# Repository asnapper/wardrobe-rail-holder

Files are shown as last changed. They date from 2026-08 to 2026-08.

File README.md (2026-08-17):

# Ceiling wardrobe rail bracket

Parametric OpenSCAD model for mounting a vertical 30 × 15 mm rounded-rectangle
wardrobe rail to a ceiling. The rail has 7 mm corner radii and is captured by a
removable lower cap.

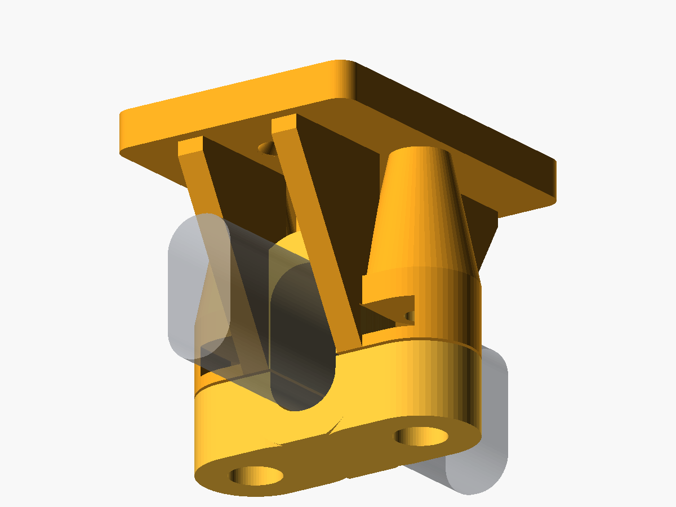
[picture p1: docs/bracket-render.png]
Rendered wardrobe rail bracket


## Hardware for one bracket

- 2 × M6 × 12 mm button-head socket screws
- 2 × standard M6 hex nuts (10 mm nominal across flats, 6 mm thick)
- 2 × 4 mm countersunk ceiling screws
- Ceiling anchors appropriate for the ceiling construction and intended load

Do not select ceiling anchors by screw size alone. Plasterboard, masonry,
concrete, timber, and suspended ceilings require different fastening methods.

## Release files

| File | Contents and intended use |
| --- | --- |
| [`dist/models/wardrobe_rail_bracket_main.stl`](dist/models/wardrobe_rail_bracket_main.stl) | Main body in its recommended print orientation; use with any slicer. |
| [`dist/models/wardrobe_rail_bracket_cap.stl`](dist/models/wardrobe_rail_bracket_cap.stl) | Cap in its recommended print orientation; use with any slicer. |
| [`dist/models/wardrobe_rail_bracket_main.3mf`](dist/models/wardrobe_rail_bracket_main.3mf) | Neutral, portable 3MF containing the main body only. |
| [`dist/models/wardrobe_rail_bracket_cap.3mf`](dist/models/wardrobe_rail_bracket_cap.3mf) | Neutral, portable 3MF containing the cap only. |
| [`dist/models/wardrobe_rail_bracket_complete.3mf`](dist/models/wardrobe_rail_bracket_complete.3mf) | Neutral, portable print layout containing one main body and one cap. |
| [`dist/wardrobe_rail_bracket_P1S_0.4_PLA_2x.gcode.3mf`](dist/wardrobe_rail_bracket_P1S_0.4_PLA_2x.gcode.3mf) | Ready-to-print Bambu Lab P1S project for two complete brackets, with models, project settings, and printer toolpaths. |

The P1S project was sliced with OrcaSlicer 2.4.2 for a P1S with a 0.4 mm
nozzle, Textured PEI Plate, and Bambu PLA Basic. It contains four objects: two
main bodies and two caps. Its embedded profile uses 0.20 mm layers, 5 walls, 6
top and bottom layers, 40% gyroid infill, a 5 mm outer brim with a 0.1 mm gap,
and no supports. OrcaSlicer reports 250 layers, 169.15 g of filament, and
22,314 s (about 6 h 12 min) estimated print time.

The headless P1S build is intended to reproduce the project settings and
toolpaths; embedded thumbnails are not guaranteed. Review the selected filament
and build plate in OrcaSlicer before sending it to the printer.

OrcaSlicer retains its standard enclosed-printer PLA advisory because the stock
Textured PEI profile uses a 55 °C bed. For this long PLA print, open the P1S
front door and/or remove the upper glass so chamber heat does not soften the
filament and cause an extruder clog. The advisory is intentionally retained; the
material heat limit and official bed temperature have not been falsified to hide
it.

## Reproducing release assets

Install [Python 3](https://www.python.org/downloads/),
[OpenSCAD](https://openscad.org/downloads.html), and
[OrcaSlicer 2.4 or later](https://github.com/OrcaSlicer/OrcaSlicer/releases).
Python 3 runs the standard-library artifact validator that checks every staged
model and sliced project before any release file is replaced.
[`xvfb-run`](https://packages.ubuntu.com/search?keywords=xvfb) is optional for
the aggregate release build: without it, `build-all.sh` still builds the models
and P1S project but preserves the existing render. It is required whenever
`build-render.sh` regenerates the PNG, including on a machine with a display.

Run the individual builders from the repository root:

```bash
./scripts/build-models.sh  # neutral STL and 3MF files in dist/models
./scripts/build-p1s.sh     # sliced P1S .gcode.3mf in dist
./scripts/build-render.sh  # regenerates docs/bracket-render.png; requires Xvfb
./scripts/build-all.sh     # models and P1S project; regenerates render if Xvfb is available
```

The builders locate `python3`, `openscad`, `orca-slicer` (also `orcaslicer` or
`OrcaSlicer`), and `xvfb-run` on `PATH`. Set `PYTHON_BIN`, `OPENSCAD_BIN`,
`ORCASLICER_BIN`, or `XVFB_RUN_BIN` to executable paths to override those
selections, for example:

```bash
PYTHON_BIN=/opt/python/bin/python3 ./scripts/build-models.sh
OPENSCAD_BIN=/opt/OpenSCAD/openscad ./scripts/build-models.sh
ORCASLICER_BIN=/opt/OrcaSlicer/orca-slicer ./scripts/build-p1s.sh
XVFB_RUN_BIN=/usr/bin/xvfb-run ./scripts/build-render.sh
```

`build-models.sh` accepts `--output-dir DIR`; `build-p1s.sh` and
`build-render.sh` accept `--output FILE`. `build-all.sh` has no arguments. If
Xvfb is unavailable, `build-all.sh` warns and keeps the existing render rather
than replacing it.

## Exporting the parts

Open `wardrobe_rail_bracket.scad` in OpenSCAD and set `part` near the top of the
file:

```scad
part = "main_print"; // main part in its recommended print orientation
part = "cap_print";  // cap in its recommended print orientation
```

The default `part = "print"` places both pieces on the build plate in their
recommended orientations. `part = "assembly"` shows the installed arrangement;
OpenSCAD preview also displays a translucent reference rail.

Command-line export is supported:

```bash
openscad -o wardrobe-bracket-main.stl -D 'part="main_print"' wardrobe_rail_bracket.scad
openscad -o wardrobe-bracket-cap.stl -D 'part="cap_print"' wardrobe_rail_bracket.scad
```

The `main` and `cap` modes retain the installed assembly coordinates and are
useful for CAD inspection rather than direct slicing.

All principal dimensions are top-level parameters. The default rail socket is
30.6 × 15.6 mm with a 7.3 mm radius, providing 0.3 mm nominal clearance on each
side, and the top of the rail sits 30 mm below the ceiling-contact plane. Print
a short fit sample or adjust `rail_clearance` if the printer or rail needs a
different tolerance.

## Suggested PLA print settings

- 0.2 mm layer height or finer
- At least 5 perimeters/walls
- At least 6 top and bottom layers
- 40–60% cubic or gyroid infill
- No supports should be required in the supplied print layout; inspect the
  preview for the selected printer and slicer

The main part prints with its ceiling-contact face on the bed. The cap has a
flattened exterior face for bed adhesion; its downward-facing bolt-head recesses
start at that face and print upward from the build plate. Avoid changing these
orientations casually: layer direction is part of the load-bearing design.

PETG or another tougher, more creep-resistant material is preferable for warm
locations or long-term heavy loading. If using a material other than PLA,
re-check hole and rail clearances with a fit sample.

## Assembly

1. Slide one standard M6 nut into each side-loading hexagonal pocket in the
   main body.
2. Fasten the main body to structural ceiling material using both countersunk
   holes and suitable anchors.
3. Lift the rail into the downward-facing upper saddle.
4. Place the lower cap around the rail, with its bolt-head recesses facing down.
5. Insert the two M6 × 12 mm button-head bolts and tighten them evenly. Stop
   once the cap is secure; do not crush the rail or strip the printed part.

The 0.6 mm gap between the body and cap provides take-up for tolerance. A small
visible gap after tightening is normal.

## Safety and loading

The previous 10 mm-ceiling-gap M6 revision was printed successfully. The current
30 mm-ceiling-gap geometry has **not yet been physically or load verified**; the
earlier print does not validate this taller revision. A 20 kg static load is a
design target only, not a validated capacity or safety claim. It is **not
structurally certified**. Capacity depends on filament quality and age, print
temperature, layer adhesion, bracket spacing, rail span, ambient heat, ceiling
construction, screws, and anchors. PLA also creeps under sustained load.

Use multiple brackets, keep people clear during testing, and proof-load the
installed rail gradually with a non-fragile load before hanging clothes. Inspect
the brackets periodically for cracks, loosening, distortion, or cap movement.
Do not use the model where failure could injure someone or for human-supporting,
overhead lifting, or safety-critical applications.

## Verification

Run the automated render checks with:

```bash
python3 -m unittest discover -s tests -v
```

The tests compile every output mode with OpenSCAD, inspect the binary STL
envelopes and screw-access paths, exercise custom rail dimensions, verify
invalid geometry is rejected, and validate the embedded P1S settings and G-code
checksum in the ready-to-print project.

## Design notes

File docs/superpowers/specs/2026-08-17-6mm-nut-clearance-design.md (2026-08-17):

# 6 mm Nut Clearance Design

**Status:** Approved for implementation on 2026-08-17

## Goal

Fit the user's 6 mm-high M6 hex nuts in the main body's side-loading captive
nut pockets while preserving the model's existing 0.3 mm nominal print
clearance.

## Selected Approach

Change the authoritative `clamp_nut_thickness` parameter from 5 mm to 6 mm and
leave `nut_clearance` at 0.3 mm. The derived `nut_pocket_height` therefore
changes from 5.3 mm to 6.3 mm. This represents the real hardware dimension and
keeps custom parameter behavior predictable.

The pocket bottom, bearing floor, roof thickness, across-flats dimension, and
lateral clearance remain unchanged. The pocket top, main lug top, and tapered
boss support adjust through the existing derived dimensions, raising the
pocket roof by exactly 1 mm without reducing the 2.5 mm nut floor or 6 mm nut
roof.

The M6 x 12 mm clamp screws remain unchanged at the user's request. With the
taller pocket, a nominal screw reaches 0.1 mm beyond the pocket top and 0.4 mm
beyond a 6 mm nut seated on the pocket floor. Recalibrate
`minimum_bolt_projection` from 0.8 mm to 0 mm so the model requires the screw
to reach the full pocket height without claiming a protrusion margin that the
selected hardware cannot provide.

## Model and Hardware Contract

- Default hardware uses two M6 hex nuts measuring 10 mm nominal across flats
  and 6 mm high.
- Each captive pocket is 6.3 mm high: 6 mm nominal hardware plus 0.3 mm
  clearance.
- The existing M6 x 12 mm button-head screws, pocket loading direction, bolt
  axis, and rail geometry remain unchanged.
- The bolt-length assertion requires the screw to reach the full pocket height;
  it does not require additional projection beyond the 6.3 mm pocket.
- Existing structural assertions must still pass with the raised pocket roof.

## Tests

Update the real-geometry hardware fit test before changing the model so its
6 mm nut probe fails against the current 5.3 mm pocket. After the parameter
change, the same probe must occupy and enter each pocket without intersecting
the main body. The existing short-bolt rejection must still prove that an
undersized screw cannot reach the full pocket. Existing rendering, topology,
envelope, support, and invalid-parameter tests remain regression coverage.

Run the complete unit-test suite after rebuilding release artifacts. Validate
the neutral models and sliced P1S project with the repository's release
validator.

## Documentation and Release Artifacts

Update the README hardware list to specify 6 mm-high nuts. Regenerate all five
neutral model releases, the README render, and the two-bracket P1S sliced
project from the changed SCAD source. Update documented slicer layer, material,
and time estimates if the regenerated project reports different values.

The neutral model envelope contract is expected to remain unchanged because
the extra pocket height removes internal material without changing the outer
part bounds. Any actual regenerated envelope or slicer metadata changes must be
reflected in their validators and documentation rather than waived.

## Non-Goals

- Increasing clearance beyond the existing 0.3 mm allowance.
- Changing nut width, the selected M6 x 12 mm bolts, rail fit, or bracket
  exterior geometry.
- Claiming physical fit or load validation before the revised model is printed
  and tested.

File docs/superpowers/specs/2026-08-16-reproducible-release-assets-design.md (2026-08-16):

# Reproducible Release Assets Design

**Status:** Approved for implementation on 2026-08-16

## Goal

Provide current M6 model files suitable for MakerWorld, Printables, and other
model hosts, and make every published artifact reproducible from
`wardrobe_rail_bracket.scad` with command-line scripts. Mandatory builds must
work without a display server. Image generation may use Xvfb when available,
but must remain optional.

## Current State

The parametric SCAD model is the authoritative source. The repository currently
publishes one Bambu P1S two-bracket `.gcode.3mf` under `dist/`, but it has no
current standalone main/cap model exports. The tracked root
`wardrobe_rail_bracket.3mf` predates the M6 redesign, and an ignored root
`wardrobe_rail_bracket.stl` is also obsolete. Both root artifacts can be
mistaken for the current release and must be removed.

The existing README render is current, but its generation previously required
a manually assembled OpenSCAD/Xvfb command. The new scripts must make that
operation discoverable and repeatable without making Xvfb a mandatory build
dependency.

## Selected Approach

OpenSCAD owns all portable geometry exports because it can generate STL and
standards-based geometry-only 3MF files directly from the SCAD source without a
display server. OrcaSlicer 2.4 or newer owns only the printer-specific P1S
`.gcode.3mf`. OpenSCAD running under Xvfb owns the optional README render.

This division keeps neutral model downloads independent of a slicer, avoids
slicer metadata in clean 3MF files, and provides a headless route for the
printer-specific artifact. It also keeps the SCAD output modes as the single
definition of print orientation.

## Artifact Contract

Generated release files live under `dist/`:

```text
dist/
|-- models/
|   |-- wardrobe_rail_bracket_main.stl
|   |-- wardrobe_rail_bracket_cap.stl
|   |-- wardrobe_rail_bracket_main.3mf
|   |-- wardrobe_rail_bracket_cap.3mf
|   `-- wardrobe_rail_bracket_complete.3mf
`-- wardrobe_rail_bracket_P1S_0.4_PLA_2x.gcode.3mf
```

The main and cap files use `part="main_print"` and `part="cap_print"`, so each
part sits on the build plate in its recommended orientation. The complete 3MF
uses `part="print"` and contains one main plus one cap in their recommended
layout. All three 3MF files under `dist/models/` are unsliced geometry-only
archives: they contain no G-code and no OrcaSlicer or Bambu Studio project
settings.

The P1S `.gcode.3mf` contains two complete brackets: two main bodies and two
caps. It preserves the agreed P1S, 0.4 mm nozzle, Bambu PLA Basic, and Textured
PEI configuration with these project settings:

- 0.20 mm layer height
- 5 walls
- 6 top layers and 6 bottom layers
- 40% gyroid infill
- supports disabled
- 5 mm outer brim with 0.1 mm object gap
- by-layer printing
- 120 mm/s outer walls and 200 mm/s inner walls/infill

The tracked pre-M6 root 3MF is deleted. The ignored pre-M6 root STL is removed
from the workspace. `.gitignore` continues to ignore incidental STL exports but
allows the five deliberate model releases under `dist/models/` to be tracked.

## Script Interfaces

The build interface consists of focused POSIX shell scripts:

```text
scripts/
|-- lib/common.sh
|-- build-models.sh
|-- build-p1s.sh
|-- build-render.sh
`-- build-all.sh
```

`scripts/lib/common.sh` resolves repository paths, locates executables, prints
consistent diagnostics, creates temporary working directories, and installs
completed artifacts atomically. It never deletes paths outside the known
release targets.

`scripts/build-models.sh` requires OpenSCAD and regenerates all five files under
`dist/models/`. It accepts an optional `--output-dir DIR` for tests and local
experiments; its default is the repository release directory.

`scripts/build-p1s.sh` requires OpenSCAD and OrcaSlicer 2.4 or newer. It first
exports fresh main/cap STL inputs into a temporary directory, loads the
repository's versioned Orca profiles, creates two copies of each part, arranges
them on one P1S plate, slices the plate, validates the result, and atomically
replaces the published `.gcode.3mf`. It accepts an optional `--output FILE` for
verification builds. It does not consume model files already present under
`dist/`, so a stale intermediate export cannot enter the sliced release.

`scripts/build-render.sh` explicitly regenerates
`docs/bracket-render.png`. It requires OpenSCAD and `xvfb-run`; when invoked
directly, a missing Xvfb dependency is an actionable error.

`scripts/build-all.sh` runs the neutral model and P1S builds. It then invokes
the render build only when `xvfb-run` is available. If Xvfb is absent, it emits
a warning, leaves the existing image unchanged, and completes successfully.

The Orca command runs directly in a headless environment. When `xvfb-run` is
available, the script may use it to enable embedded graphical previews. A
headless archive without embedded thumbnails remains valid; thumbnails are not
part of the mandatory P1S artifact contract.

## Slicer Profiles

Versioned, flattened CLI inputs live under `profiles/orca/`:

```text
profiles/orca/
|-- p1s-0.4-machine.json
|-- pla-basic.json
`-- bracket-strength.json
```

The files make the build independent of a user's OrcaSlicer presets and encode
the machine, filament, and project settings required by the artifact contract.
They are input data, not generated release outputs. OrcaSlicer records its
actual version in the exported project; the scripts reject versions older than
2.4 because reliable headless export is a design requirement.

## Dependency Discovery and Diagnostics

Executable lookup follows this order:

1. An explicit environment override.
2. Supported executable names on `PATH`.
3. Failure with a concise diagnostic and official installation link.

Supported overrides are `OPENSCAD_BIN`, `ORCASLICER_BIN`, and `XVFB_RUN_BIN`.
Orca lookup recognizes common names such as `orca-slicer`, `OrcaSlicer`, and
`orcaslicer`; an AppImage can be selected with `ORCASLICER_BIN=/path/to/file`.

Diagnostics identify which command is missing and point to:

- OpenSCAD downloads: <https://openscad.org/downloads.html>
- OrcaSlicer releases: <https://github.com/OrcaSlicer/OrcaSlicer/releases>
- Xvfb package information: <https://packages.ubuntu.com/search?keywords=xvfb>

Missing OpenSCAD stops every build that needs geometry. Missing OrcaSlicer
stops only the P1S and aggregate release builds. Missing Xvfb stops an explicit
render build but merely skips rendering in the aggregate build.

All scripts use a temporary directory and validate complete outputs before
moving them into place. A failed OpenSCAD render, failed slice, nonzero Orca
result, empty file, malformed ZIP archive, or missing expected payload exits
nonzero and leaves the previous published artifact untouched.

## Validation and Tests

Tests exercise observable build behavior rather than searching script source
for expected strings.

Model export integration tests run `build-models.sh` against a temporary output
directory and verify:

- all five artifacts exist and are nonempty;
- STL and 3MF meshes have the expected M6 model envelopes;
- individual parts are manifold and rest on the build plate;
- the complete 3MF contains both printable volumes;
- clean 3MF archives contain no G-code, slice information, or slicer-project
  configuration.

Dependency tests invoke scripts with deliberately unavailable executable
overrides and verify a nonzero exit, the missing dependency name, an official
installation URL, and the absence of partial output.

The existing P1S tests continue to verify four printable objects, valid embedded
G-code and checksum, exact strength settings, support-free toolpaths, plausible
material/time estimates, and current M6 geometry. Preview-image assertions are
relaxed so a valid headless Orca export is accepted. When OrcaSlicer is present,
a release smoke test regenerates the P1S artifact into a temporary path and
runs the same archive validation against it.

A repository hygiene test verifies that neither obsolete root model artifact
exists. The complete suite remains runnable with:

```bash
python3 -m unittest discover -s tests -v
```

## Documentation

The README gains a release-files table and a regeneration section that lists
each script, its output, its required dependencies, environment overrides, and
the optional Xvfb behavior. The ready-to-print section identifies OrcaSlicer as
the generator after migration and reports estimates obtained from the newly
generated artifact rather than retaining Bambu Studio values.

The documentation does not claim physical validation of the M6 revision. Fit,
function, sustained loading, and installation testing remain pending until the
part has been printed and mounted.

## Non-Goals

- Changing bracket geometry or hardware dimensions.
- Claiming verified fit, function, load capacity, or long-term material safety.
- Adding printer profiles other than the P1S 0.4 mm PLA release.
- Downloading or installing dependencies automatically.
- Requiring X11, Wayland, Xvfb, or OpenGL for mandatory model and slicing
  outputs.
- Guaranteeing byte-for-byte identical ZIP archives across slicer versions.

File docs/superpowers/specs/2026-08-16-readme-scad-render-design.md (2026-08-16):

# README SCAD render design

## Goal

Replace the inaccurate `docs/bracket-arrangement.svg` illustration with an
image rendered from the current OpenSCAD geometry.

## Design

- Render `part="assembly"` directly from `wardrobe_rail_bracket.scad`.
- Use an orthographic three-quarter camera angle that clearly shows the ceiling
  plate, upper body, removable cap, fastener locations, and reference rail.
- Use a neutral background and the model's existing material colors.
- Save the result as `docs/bracket-render.png` at a README-friendly resolution.
- Update the README image reference, then remove the obsolete SVG.

## Verification

- Visually inspect the rendered PNG against the SCAD assembly.
- Confirm the PNG is valid and sufficiently large for the README.
- Confirm the README references the new image and no tracked file references the
  removed SVG.
- Run the existing automated tests to ensure the documentation-only change does
  not disturb the model or packaged print project.

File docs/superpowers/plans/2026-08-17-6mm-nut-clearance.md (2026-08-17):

# 6 mm Nut Clearance Implementation Plan

> **For agentic workers:** REQUIRED SUB-SKILL: Use superpowers:subagent-driven-development (recommended) or superpowers:executing-plans to implement this plan task-by-task. Steps use checkbox (`- [ ]`) syntax for tracking.

**Goal:** Increase the default captive-nut pocket from 5.3 mm to 6.3 mm so a 6 mm-high M6 nut fits with the existing 0.3 mm nominal print clearance, and refresh every published artifact derived from that geometry.

**Architecture:** `wardrobe_rail_bracket.scad` remains the authoritative geometry source. A real-geometry OpenSCAD intersection probe specifies the required nut fit, existing derived dimensions propagate the 1 mm increase through the lug and boss, and the established build scripts regenerate and validate neutral, rendered, and sliced releases.

**Tech Stack:** OpenSCAD, Python 3 `unittest`, POSIX shell build scripts, OrcaSlicer 2.4.2, Xvfb, STL/3MF/PNG release artifacts.

## Global Constraints

- Default nut hardware is 10 mm nominal across flats and 6 mm high.
- Preserve `nut_clearance = 0.3`, producing `nut_pocket_height = 6.3` mm.
- Preserve the pocket bottom, 2.5 mm bearing floor, 6 mm roof, loading direction, bolt axis, M6 x 12 mm button-head screws, and rail geometry.
- Recalibrate `minimum_bolt_projection` from 0.8 mm to 0 mm: the 12 mm bolt must reach the full 6.3 mm pocket, with nominal geometry extending 0.1 mm beyond the pocket and 0.4 mm beyond a seated 6 mm nut.
- Do not claim physical fit or load validation; the revised part remains unprinted and unverified.
- Regenerate all five neutral model releases, the 1200 x 900 README render, and the two-bracket P1S sliced project.
- Keep the existing external mesh-envelope contracts unless regenerated geometry proves an actual outer-bound change.

## File Map

- `wardrobe_rail_bracket.scad`: authoritative hardware parameter and derived pocket/lug geometry.
- `tests/test_scad_model.py`: real-geometry bolt and nut fit regression test.
- `README.md`: hardware contract and measured OrcaSlicer release estimates.
- `dist/models/*`: five regenerated neutral STL/3MF model releases.
- `docs/bracket-render.png`: regenerated assembly image.
- `dist/wardrobe_rail_bracket_P1S_0.4_PLA_2x.gcode.3mf`: regenerated two-bracket P1S project.
- `tests/test_3mf_project.py`: plausibility contract for the regenerated sliced project's measured weight and time.

---

### Task 1: Specify and implement the 6.3 mm captive-nut pocket

**Files:**
- Modify: `tests/test_scad_model.py:240-267`
- Modify: `wardrobe_rail_bracket.scad:44-46`
- Modify: `README.md:9-13`

**Interfaces:**
- Consumes: `OpenScadRenderTests.render(output_mode, *definitions)` and `assert_probe_does_not_intersect(model_output, probe_body, message)`.
- Produces: default `clamp_nut_thickness = 6`, derived `nut_pocket_height = 6.3`, `minimum_bolt_projection = 0`, and a hardware-fit regression using a 5.96 mm geometric probe inset 0.02 mm from the nominal 6 mm faces to avoid coincident-surface ambiguity.

- [ ] **Step 1: Change the regression probe to represent a 6 mm-high nut**

In both nut solids inside `test_m6_button_head_bolt_and_standard_nut_fit_the_voids`, change only the heights from `4.96` to `5.96`:

```python
f" translate([{bolt_x}, 0, -27.48]) cylinder(h=5.96, r=10/sqrt(3), $fn=6);"
f" translate([{bolt_x - 10 / 3 ** 0.5}, -12.98, -27.48])"
f" cube([{20 / 3 ** 0.5}, 12.96, 5.96]);"
```

- [ ] **Step 2: Run the focused test and verify RED**

Run:

```bash
python3 -m unittest tests.test_scad_model.OpenScadRenderTests.test_m6_button_head_bolt_and_standard_nut_fit_the_voids -v
```

Expected: FAIL for the standard-hex-nut subtests with `standard M6 nut cannot occupy or enter the captive pocket`, proving the current 5.3 mm pocket rejects the 6 mm nut probe.

- [ ] **Step 3: Make the minimal authoritative model change**

Change the public hardware dimension without changing the clearance formula:

```scad
clamp_nut_across_flats = 10;
clamp_nut_thickness = 6;
nut_clearance = 0.3;
minimum_bolt_projection = 0;
```

Leave these derived expressions and the full-pocket bolt-length assertion
unchanged:

```scad
nut_pocket_height = clamp_nut_thickness + nut_clearance;
assert(
    bolt_tip_z - nut_pocket_top_z >= minimum_bolt_projection,
    "clamp bolt is too short to engage the captive nut"
);
```

- [ ] **Step 4: Update the documented hardware contract**

Change the README hardware bullet to:

```markdown
- 2 × standard M6 hex nuts (10 mm nominal across flats, 6 mm thick)
```

- [ ] **Step 5: Run the focused test and SCAD regression suite to verify GREEN**

Run:

```bash
python3 -m unittest tests.test_scad_model.OpenScadRenderTests.test_m6_button_head_bolt_and_standard_nut_fit_the_voids -v
python3 -m unittest tests.test_scad_model -v
```

Expected: the focused test passes for both nut pockets and all `test_scad_model` tests pass, including bolt engagement, support, topology, and envelope checks.

- [ ] **Step 6: Commit the tested source contract**

```bash
git add wardrobe_rail_bracket.scad tests/test_scad_model.py README.md
git commit -m "fix: fit 6 mm captive nuts"
```

---

### Task 2: Regenerate neutral models and the README render

**Files:**
- Modify: `dist/models/wardrobe_rail_bracket_main.stl`
- Modify: `dist/models/wardrobe_rail_bracket_cap.stl`
- Modify: `dist/models/wardrobe_rail_bracket_main.3mf`
- Modify: `dist/models/wardrobe_rail_bracket_cap.3mf`
- Modify: `dist/models/wardrobe_rail_bracket_complete.3mf`
- Modify: `docs/bracket-render.png`

**Interfaces:**
- Consumes: the default SCAD output modes `main_print`, `cap_print`, `print`, and `assembly`; `scripts/validate_release.py models DIRECTORY`.
- Produces: current neutral release geometry and a 1200 x 900 assembly PNG generated from the 6.3 mm-pocket source.

- [ ] **Step 1: Regenerate and validate all neutral model releases**

Run:

```bash
./scripts/build-models.sh
python3 scripts/validate_release.py models dist/models
```

Expected: both commands exit 0. The main, cap, and complete artifacts retain their existing 63.5 x 75.0 x 30.0, 63.5 x 24.0 x 15.7, and 133.5 x 75.0 x 30.0 envelope contracts respectively.

- [ ] **Step 2: Regenerate the README render from the changed source**

Run:

```bash
./scripts/build-render.sh
```

Expected: exit 0 and `docs/bracket-render.png` is replaced by a nonempty 1200 x 900 PNG.

- [ ] **Step 3: Verify the release builders and render contract**

Run:

```bash
python3 -m unittest tests.test_release_scripts tests.test_readme_render -v
```

Expected: all tests pass, including model topology, geometry-only 3MF contents, atomic publication behavior, and PNG dimensions.

- [ ] **Step 4: Review and commit generated neutral assets**

Run `git status --short` and confirm changes are limited to expected regenerated files. Git may omit byte-identical cap or render outputs; their successful build commands are the evidence that they were regenerated.

```bash
git add dist/models docs/bracket-render.png
git commit -m "build: refresh 6 mm nut model assets"
```

---

### Task 3: Regenerate the sliced P1S project and synchronize measured metadata

**Files:**
- Modify: `dist/wardrobe_rail_bracket_P1S_0.4_PLA_2x.gcode.3mf`
- Modify: `README.md:30-35`
- Modify if measured estimates leave the current accepted ranges: `tests/test_3mf_project.py:109-128`

**Interfaces:**
- Consumes: current main/cap SCAD geometry, versioned P1S/PLA/strength profiles, and `scripts/validate_release.py p1s ARCHIVE`.
- Produces: a four-object sliced project with two main bodies, two caps, 150 support-free layers, valid embedded G-code checksum, and README/test estimates matching the regenerated archive.

- [ ] **Step 1: Regenerate and validate the P1S project**

Run:

```bash
./scripts/build-p1s.sh
python3 scripts/validate_release.py p1s dist/wardrobe_rail_bracket_P1S_0.4_PLA_2x.gcode.3mf
```

Expected: both commands exit 0; validation confirms two main and two cap objects, correct 63.5 mm object widths, 150 support-free layers, expected profiles, and a matching embedded checksum.

- [ ] **Step 2: Read the regenerated weight and time from the archive**

Run:

```bash
python3 -c 'import zipfile,xml.etree.ElementTree as E; p="dist/wardrobe_rail_bracket_P1S_0.4_PLA_2x.gcode.3mf"; z=zipfile.ZipFile(p); r=E.fromstring(z.read("Metadata/slice_info.config")); m={e.attrib.get("key"):e.attrib.get("value") for e in r.findall("./plate/metadata")}; print("weight_g="+m["weight"], "prediction_s="+m["prediction"])'
```

Expected: one `weight_g` value and one `prediction_s` value from OrcaSlicer. Convert seconds to rounded hours/minutes using integer division for the README parenthetical.

- [ ] **Step 3: Verify whether the old plausibility contract detects the changed sliced output**

Run:

```bash
python3 -m unittest tests.test_3mf_project.OrcaProjectTests.test_slice_is_support_free_and_has_plausible_estimates -v
```

Expected: either PASS if the reduced-material project remains inside both existing narrow ranges, or FAIL specifically on the weight/time range whose regenerated value moved outside it. Do not alter support, outside-bed, layer-count, or support-toolpath assertions.

- [ ] **Step 4: Synchronize README measurements and, only when needed, plausibility bounds**

Replace the README's `133.09 g`, `17,452 s`, and rounded duration with the values printed in Step 2, retaining `150 layers`.

If a Step 3 bound failed, replace only that pair of bounds with a narrow deterministic interval around the measured result:

- Weight: the immediately enclosing 0.2 g interval on one-decimal boundaries; for example, a measured 132.67 g uses `> 132.6` and `< 132.8`.
- Time: the immediately enclosing 100-second interval; for example, 17,389 s uses `> 17_300` and `< 17_400`.

This keeps the test independent of README formatting while allowing small deterministic slicer variation.

- [ ] **Step 5: Verify the sliced project and its documentation**

Run:

```bash
python3 -m unittest tests.test_3mf_project -v
python3 scripts/validate_release.py p1s dist/wardrobe_rail_bracket_P1S_0.4_PLA_2x.gcode.3mf
```

Expected: all project tests pass and the release validator exits 0.

- [ ] **Step 6: Commit the regenerated sliced release and synchronized metadata**

```bash
git add dist/wardrobe_rail_bracket_P1S_0.4_PLA_2x.gcode.3mf README.md tests/test_3mf_project.py
git commit -m "build: refresh 6 mm nut P1S project"
```

---

### Task 4: Full repository verification

**Files:**
- Verify only; modify a scoped source, test, documentation, or artifact file only if its corresponding verification exposes a requirement mismatch.

**Interfaces:**
- Consumes: all source, tests, generated artifacts, and validators updated in Tasks 1-3.
- Produces: fresh evidence that the repository is internally consistent and releasable.

- [ ] **Step 1: Run the complete automated test suite**

Run:

```bash
python3 -m unittest discover -s tests -v
```

Expected: all discovered tests pass with zero failures and zero errors.

- [ ] **Step 2: Re-run both release validators directly**

Run:

```bash
python3 scripts/validate_release.py models dist/models
python3 scripts/validate_release.py p1s dist/wardrobe_rail_bracket_P1S_0.4_PLA_2x.gcode.3mf
```

Expected: both commands exit 0 without diagnostics.

- [ ] **Step 3: Check patch hygiene and scope**

Run:

```bash
git diff --check HEAD~3..HEAD
git status --short
```

Expected: no whitespace errors and no uncommitted changes. Review `git show --stat --oneline HEAD~3..HEAD` to confirm the implementation touched only the files listed in this plan.

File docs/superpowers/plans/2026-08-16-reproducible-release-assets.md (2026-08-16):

# Reproducible Release Assets Implementation Plan

> **For agentic workers:** REQUIRED SUB-SKILL: Use superpowers:subagent-driven-development (recommended) or superpowers:executing-plans to implement this plan task-by-task. Steps use checkbox (`- [ ]`) syntax for tracking.

**Goal:** Replace obsolete pre-M6 model files with current portable STL/3MF releases and add a headless, reproducible OpenSCAD/OrcaSlicer build pipeline for every published artifact.

**Architecture:** OpenSCAD exports neutral geometry directly from the SCAD output modes. Focused POSIX shell scripts share dependency discovery and atomic-install helpers; OrcaSlicer 2.4+ consumes committed flattened P1S profiles only for the sliced two-bracket release. Tests run the real model exporter, inspect generated archives and meshes, and exercise dependency failures at process boundaries.

**Tech Stack:** OpenSCAD 2021.01+, POSIX shell, OrcaSlicer 2.4+, Python 3 standard-library `unittest`, STL parsing, XML, and ZIP inspection; optional Xvfb.

## Global Constraints

- Work directly on `master`, preserving unrelated user changes.
- `wardrobe_rail_bracket.scad` remains the authoritative geometry source.
- Mandatory model and slicing outputs must not require X11, Wayland, Xvfb, or OpenGL.
- Image generation may use Xvfb but must be optional in the aggregate build.
- Model files under `dist/models/` are geometry-only and contain no slicer settings or G-code.
- The P1S release contains two mains and two caps with 0.20 mm layers, 5 walls, 6 top/bottom layers, 40% gyroid, supports disabled, 5 mm outer brim, 0.1 mm brim gap, by-layer printing, 120 mm/s outer walls, and 200 mm/s inner walls/infill.
- Missing dependencies must name the executable, exit nonzero when required, preserve prior outputs, and provide an official installation link.
- Delete both obsolete root artifacts: tracked `wardrobe_rail_bracket.3mf` and ignored `wardrobe_rail_bracket.stl`.
- Do not claim that the M6 revision has been physically tested.

---

### Task 1: Neutral model export contract

**Files:**
- Create: `tests/test_release_scripts.py`
- Create: `scripts/lib/common.sh`
- Create: `scripts/build-models.sh`
- Modify: `.gitignore`

**Interfaces:**
- Consumes: SCAD modes `main_print`, `cap_print`, and `print`.
- Produces: `scripts/build-models.sh [--output-dir DIR]` and helper functions `find_required_tool`, `new_build_dir`, `require_nonempty`, and `atomic_install`.

- [ ] **Step 1: Write failing integration tests for portable exports**

Add `ReleaseModelBuildTests` that runs `scripts/build-models.sh --output-dir <temp>`, expects the five literal filenames from the spec, parses the real STL and 3MF vertices, and asserts these hand-derived envelopes:

```python
EXPECTED = {
    "wardrobe_rail_bracket_main.stl": ((63.5, 75.0, 30.0), 1),
    "wardrobe_rail_bracket_cap.stl": ((63.5, 24.0, 15.7), 1),
    "wardrobe_rail_bracket_main.3mf": ((63.5, 75.0, 30.0), 1),
    "wardrobe_rail_bracket_cap.3mf": ((63.5, 24.0, 15.7), 1),
}
```

The 75 mm Y extent is the full ceiling plate; 24 mm is only the clamp depth.

For `wardrobe_rail_bracket_complete.3mf`, assert two disconnected printable volumes, nonnegative Z, no path ending in `.gcode`, and absence of `Metadata/project_settings.config`, `Metadata/model_settings.config`, and `Metadata/slice_info.config`.

- [ ] **Step 2: Run the model-script tests and verify RED**

Run:

```bash
python3 -m unittest tests.test_release_scripts.ReleaseModelBuildTests -v
```

Expected: FAIL because `scripts/build-models.sh` does not exist.

- [ ] **Step 3: Write failing dependency and atomicity tests**

Run the missing script with `OPENSCAD_BIN=/definitely/missing/openscad` and a temporary output directory containing a sentinel file. Assert nonzero status, stderr containing `OpenSCAD` and `https://openscad.org/downloads.html`, the sentinel unchanged, and no release filenames created.

- [ ] **Step 4: Implement common helpers and the neutral exporter**

Implement executable resolution without `eval`:

```sh
find_required_tool() {
    override=$1 label=$2 url=$3
    shift 3
    if [ -n "$override" ]; then
        [ -x "$override" ] || die "$label executable not found: $override\nInstall: $url"
        printf '%s\n' "$override"
        return
    fi
    for candidate do
        if command -v "$candidate" >/dev/null 2>&1; then
            command -v "$candidate"
            return
        fi
    done
    die "$label is required but was not found. Install: $url"
}
```

`build-models.sh` resolves the repository root from its own path, accepts only `--output-dir DIR`, exports each requested SCAD mode into a private `mktemp -d` directory, checks every file is nonempty, then installs all five outputs only after all exports succeed. Use OpenSCAD itself for both STL and 3MF; do not route clean 3MF through a slicer.

- [ ] **Step 5: Allow deliberate release STLs and run GREEN**

Keep `*.stl` ignored and add:

```gitignore
!dist/models/
!dist/models/*.stl
```

Make scripts executable, rerun the focused tests, and expect PASS.

- [ ] **Step 6: Commit the neutral pipeline**

```bash
git add .gitignore scripts/lib/common.sh scripts/build-models.sh tests/test_release_scripts.py
git commit -m "build: add portable model export pipeline"
```

### Task 2: Current model artifacts and stale-file removal

**Files:**
- Modify: `tests/test_release_scripts.py`
- Create: `dist/models/wardrobe_rail_bracket_main.stl`
- Create: `dist/models/wardrobe_rail_bracket_cap.stl`
- Create: `dist/models/wardrobe_rail_bracket_main.3mf`
- Create: `dist/models/wardrobe_rail_bracket_cap.3mf`
- Create: `dist/models/wardrobe_rail_bracket_complete.3mf`
- Delete: `wardrobe_rail_bracket.3mf`
- Delete: `wardrobe_rail_bracket.stl`

**Interfaces:**
- Consumes: `scripts/build-models.sh` from Task 1.
- Produces: the clean, current M6 release set and the repository invariant that no root model artifact exists.

- [ ] **Step 1: Add a failing repository-hygiene test**

Add a test that asserts both exact root paths are absent. Name the break it catches: an obsolete or manually exported root file can be mistaken for the current M6 release.

- [ ] **Step 2: Verify RED against the two existing root artifacts**

Run the hygiene test and expect it to fail for both `wardrobe_rail_bracket.3mf` and `wardrobe_rail_bracket.stl`.

- [ ] **Step 3: Remove only the resolved obsolete targets**

Delete the two exact root files. Do not use a glob and do not remove anything under `dist/`.

- [ ] **Step 4: Generate and verify current portable releases**

Run:

```bash
scripts/build-models.sh
python3 -m unittest tests.test_release_scripts -v
```

Expected: all release-script tests PASS.

- [ ] **Step 5: Commit the artifact replacement**

```bash
git add -A wardrobe_rail_bracket.3mf dist/models
git add -f dist/models/*.stl
git commit -m "build: publish current M6 model files"
```

### Task 3: Versioned Orca P1S profiles and sliced build

**Files:**
- Create: `profiles/orca/p1s-0.4-machine.json`
- Create: `profiles/orca/pla-basic.json`
- Create: `profiles/orca/bracket-strength.json`
- Create: `scripts/build-p1s.sh`
- Modify: `scripts/lib/common.sh`
- Modify: `tests/test_release_scripts.py`
- Modify: `tests/test_3mf_project.py`

**Interfaces:**
- Consumes: OpenSCAD, OrcaSlicer CLI 2.4+, the SCAD `main_print` and `cap_print` modes, and the three flattened profile JSON files.
- Produces: `scripts/build-p1s.sh [--output FILE]` and a validated two-bracket `.gcode.3mf`.

- [ ] **Step 1: Write failing Orca dependency tests**

Invoke `build-p1s.sh --output <temp>/release.gcode.3mf` with `ORCASLICER_BIN=/definitely/missing/orca`. Assert nonzero status, `OrcaSlicer`, `https://github.com/OrcaSlicer/OrcaSlicer/releases`, no output, and an existing sentinel output remains byte-identical.

- [ ] **Step 2: Verify RED because the P1S script is absent**

Run the focused dependency test and confirm the expected missing-script failure.

- [ ] **Step 3: Commit flattened profile inputs**

Use the official OrcaSlicer 2.4.2 release profiles named `Bambu Lab P1S 0.4 nozzle`, `Bambu PLA Basic @BBL X1C`, and `0.20mm Standard @BBL X1C` as the source presets. Export their resolved CLI settings with OrcaSlicer rather than copying a user's preset directory. Split the resulting inputs into the committed machine and filament JSON files, then apply this literal process overlay in `bracket-strength.json`:

```json
{
  "layer_height": "0.2",
  "wall_loops": "5",
  "top_shell_layers": "6",
  "bottom_shell_layers": "6",
  "sparse_infill_density": "40%",
  "sparse_infill_pattern": "gyroid",
  "enable_support": "0",
  "brim_type": "outer_only",
  "brim_width": "5",
  "brim_object_gap": "0.1",
  "print_sequence": "by layer",
  "outer_wall_speed": "120",
  "inner_wall_speed": "200",
  "sparse_infill_speed": "200"
}
```

Validate the JSON with `python3 -m json.tool` and confirm the machine profile identifies `Bambu Lab P1S 0.4 nozzle` and the filament identifies Bambu PLA Basic.

- [ ] **Step 4: Implement version checking and atomic P1S generation**

Add `version_at_least 2 4 <detected>` to the shared helpers. Implement `build-p1s.sh` so it:

1. parses only `--output FILE`;
2. resolves OpenSCAD and OrcaSlicer, honoring environment overrides;
3. rejects OrcaSlicer versions before 2.4 with the official release URL;
4. exports two fresh STL source files into a private build directory;
5. supplies each STL twice to OrcaSlicer, loads the committed settings and filament JSON, arranges and ensures them on the bed, slices plate 0, exports slice data and `.gcode.3mf`;
6. checks the Orca exit code, nonempty archive, and `result.json` return code before atomic installation.

Use direct Orca execution by default. If `xvfb-run` is available, it may wrap Orca to enable thumbnails, but slicing correctness cannot depend on it.

- [ ] **Step 5: Run dependency tests GREEN, then run a real Orca build**

First rerun the missing-dependency test. Then, with OrcaSlicer 2.4.2 selected through `ORCASLICER_BIN`, run:

```bash
scripts/build-p1s.sh --output /tmp/wardrobe-release-test.gcode.3mf
```

Expected: Orca returns success and produces a valid archive containing four model objects and embedded G-code.

- [ ] **Step 6: Adapt P1S validation to Orca output**

Keep assertions on four objects, the hand-derived 63.5 mm part width, exact strength settings, supports disabled, no support toolpaths, and embedded G-code checksum. Remove the requirement that preview PNG members exist. Update estimate bounds only after reading the real Orca `result.json`; use narrow bounds around the observed result rather than copying the old Bambu estimate.

- [ ] **Step 7: Regenerate the published P1S artifact and run GREEN**

Run `scripts/build-p1s.sh`, then:

```bash
python3 -m unittest tests.test_release_scripts tests.test_3mf_project -v
```

Expected: PASS with the new Orca-generated artifact.

- [ ] **Step 8: Commit the Orca build pipeline**

```bash
git add profiles/orca scripts/build-p1s.sh scripts/lib/common.sh tests/test_release_scripts.py tests/test_3mf_project.py dist/wardrobe_rail_bracket_P1S_0.4_PLA_2x.gcode.3mf
git commit -m "build: regenerate P1S release with OrcaSlicer"
```

### Task 4: Optional render and aggregate build

**Files:**
- Create: `scripts/build-render.sh`
- Create: `scripts/build-all.sh`
- Modify: `tests/test_release_scripts.py`

**Interfaces:**
- Consumes: common dependency helpers, OpenSCAD, optional `xvfb-run`, and the model/P1S scripts.
- Produces: explicit render regeneration and an aggregate release command that skips only images when Xvfb is absent.

- [ ] **Step 1: Write failing explicit-render dependency test**

Invoke `build-render.sh --output <temp>/render.png` with `XVFB_RUN_BIN=/definitely/missing/xvfb-run`. Assert nonzero status, `Xvfb`, `https://packages.ubuntu.com/search?keywords=xvfb`, no output, and no damage to an existing sentinel.

- [ ] **Step 2: Verify RED because the render script is absent**

Run the focused test and confirm the failure is caused by the absent entry point.

- [ ] **Step 3: Implement the render script**

Accept only `--output FILE`; default to `docs/bracket-render.png`. Reuse the established 1200x900 orthographic OpenSCAD assembly camera and `Tomorrow` color scheme. Render into a private directory via `xvfb-run`, check the PNG is nonempty, and install atomically.

- [ ] **Step 4: Implement aggregate orchestration**

`build-all.sh` invokes model and P1S scripts. It calls `build-render.sh` only if the explicit `XVFB_RUN_BIN` is executable or `xvfb-run` is on `PATH`; otherwise it emits `warning: Xvfb not found; keeping existing render` and exits successfully after mandatory outputs finish.

- [ ] **Step 5: Run render tests and regenerate the image**

Run the dependency test, then `scripts/build-render.sh`, followed by the existing render dimensions test. Expect PASS and a 1200x900 PNG.

- [ ] **Step 6: Commit optional rendering**

```bash
git add scripts/build-render.sh scripts/build-all.sh tests/test_release_scripts.py docs/bracket-render.png
git commit -m "build: add optional release render generation"
```

### Task 5: Documentation, final verification, and review

**Files:**
- Modify: `README.md`
- Inspect: `tests/test_readme_render.py` (no modification expected)

**Interfaces:**
- Consumes: all generated artifacts and script entry points.
- Produces: a publication-ready file guide and reproducible build instructions without physical-validation claims.

- [ ] **Step 1: Update release documentation**

Add a table covering each `dist/models` file and the P1S profile. Add commands for `build-models.sh`, `build-p1s.sh`, `build-render.sh`, and `build-all.sh`; document OpenSCAD, OrcaSlicer 2.4+, optional Xvfb, environment overrides, official installation URLs, and the fact that headless P1S output may omit thumbnails. Replace Bambu Studio generator/estimate text with observed OrcaSlicer values. State explicitly that the M6 revision still awaits physical fit, function, and load testing.

- [ ] **Step 2: Run the full verification suite from a clean command**

Run:

```bash
python3 -m unittest discover -s tests -v
git diff --check
```

Also run `unzip -t` on all four 3MF release archives and render the two individual STLs with OpenSCAD to confirm they remain manifold.

- [ ] **Step 3: Request independent code review**

Use `superpowers:requesting-code-review` with base commit `b50b43c`. Require review of dependency behavior, atomic output safety, clean-3MF portability, P1S settings/toolpaths, stale-file removal, and README accuracy. Fix every Critical or Important finding with a failing test first.

- [ ] **Step 4: Commit documentation and review fixes**

```bash
git add README.md tests scripts profiles dist docs/bracket-render.png .gitignore
git commit -m "docs: document reproducible release builds"
```

- [ ] **Step 5: Verify the committed snapshot**

Rerun the full test suite, archive checks, `git diff --check`, and `git status --short`. The final status must be clean and `master` must contain every implementation commit.

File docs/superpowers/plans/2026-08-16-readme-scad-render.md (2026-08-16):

# README SCAD Render Implementation Plan

> **For agentic workers:** REQUIRED SUB-SKILL: Use superpowers:subagent-driven-development (recommended) or superpowers:executing-plans to implement this plan task-by-task. Steps use checkbox (`- [ ]`) syntax for tracking.

**Goal:** Replace the inaccurate README schematic with a faithful three-quarter assembly image rendered directly from the OpenSCAD model.

**Architecture:** OpenSCAD remains the single geometry source. A reproducible, documented CLI render produces `docs/bracket-render.png`; a focused documentation test validates the PNG header and dimensions, the README reference, and removal of the obsolete SVG.

**Tech Stack:** OpenSCAD 2021.01 CLI, Xvfb/software OpenGL, Python 3 standard-library `unittest`, Markdown.

## Global Constraints

- Render `part="assembly"` from `wardrobe_rail_bracket.scad`.
- Use an orthographic three-quarter view with the reference rail visible.
- Save a 1200 × 900 PNG at `docs/bracket-render.png`.
- Replace the README reference and remove `docs/bracket-arrangement.svg`.
- Do not hand-edit model geometry or the resulting bitmap.

---

### Task 1: Generate and install the faithful README render

**Files:**
- Create: `docs/bracket-render.png`
- Create: `tests/test_readme_render.py`
- Modify: `README.md:7`
- Delete: `docs/bracket-arrangement.svg`

**Interfaces:**
- Consumes: `wardrobe_rail_bracket.scad` with `part="assembly"` and its existing preview-only reference rail.
- Produces: a 1200 × 900 PNG referenced by the README and validated by `tests/test_readme_render.py`.

- [x] **Step 1: Write the failing documentation-asset test**

```python
import struct
import unittest
from pathlib import Path

ROOT = Path(__file__).resolve().parents[1]
README = ROOT / "README.md"
RENDER = ROOT / "docs" / "bracket-render.png"
OLD_SVG = ROOT / "docs" / "bracket-arrangement.svg"

class ReadmeRenderTests(unittest.TestCase):
    def test_readme_uses_current_scad_render(self):
        readme = README.read_text(encoding="utf-8")
        self.assertIn("![Rendered wardrobe rail bracket](docs/bracket-render.png)", readme)
        self.assertNotIn("docs/bracket-arrangement.svg", readme)
        self.assertFalse(OLD_SVG.exists())

    def test_render_is_a_1200_by_900_png(self):
        data = RENDER.read_bytes()
        self.assertEqual(data[:8], b"\x89PNG\r\n\x1a\n")
        self.assertEqual(data[12:16], b"IHDR")
        self.assertEqual(struct.unpack(">II", data[16:24]), (1200, 900))
```

- [x] **Step 2: Run the focused test to verify it fails**

Run: `python3 -m unittest tests.test_readme_render -v`

Expected: FAIL because `docs/bracket-render.png` does not exist and the README still references `docs/bracket-arrangement.svg`.

- [x] **Step 3: Render the assembly from OpenSCAD**

Run:

```bash
xvfb-run -a env LIBGL_ALWAYS_SOFTWARE=1 openscad \
  --preview \
  --imgsize=1200,900 \
  --projection=o \
  --camera=0,0,-24,110,0,35,250 \
  --autocenter \
  --colorscheme=Tomorrow \
  -D 'part="assembly"' \
  -o docs/bracket-render.png \
  wardrobe_rail_bracket.scad
```

Expected: OpenSCAD exits 0 and writes a 1200 × 900 PNG. Because PNG preview mode sets `$preview`, the translucent reference rail is present.

- [x] **Step 4: Visually inspect the generated image**

Open `docs/bracket-render.png` with the local image viewer. Confirm that the image shows the actual ceiling plate, upper saddle, removable cap, four bracket-bolt lugs, ceiling screw holes, and reference rail without clipping or excessive empty space. If framing is poor, adjust only the camera rotation/distance and rerender at the same output size.

- [x] **Step 5: Update the README and remove the obsolete SVG**

Change the README image line to:

```markdown
![Rendered wardrobe rail bracket](docs/bracket-render.png)
```

Delete `docs/bracket-arrangement.svg` with `apply_patch` after confirming no other tracked file references it.

- [x] **Step 6: Run focused and full verification**

Run:

```bash
python3 -m unittest tests.test_readme_render -v
python3 -m unittest discover -s tests -v
git diff --check
rg -n "bracket-arrangement\.svg|bracket-render\.png" README.md tests
```

Expected: the focused and full suites pass, `git diff --check` is silent, and only the new PNG path appears as an active README asset reference.

- [x] **Step 7: Commit the implementation**

```bash
git add README.md docs/bracket-render.png docs/bracket-arrangement.svg \
  docs/superpowers/plans/2026-08-16-readme-scad-render.md \
  tests/test_readme_render.py
git commit -m "docs: replace bracket schematic with SCAD render"
```

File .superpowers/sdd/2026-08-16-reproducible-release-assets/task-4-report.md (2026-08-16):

# Task 4 report: optional render and aggregate build

## Scope

Task 4 adds explicit render regeneration through `scripts/build-render.sh` and
the aggregate release entry point `scripts/build-all.sh`. The render keeps the
established 1200 × 900 orthographic assembly camera and `Tomorrow` color scheme,
stages the PNG in a private build directory, and installs it atomically.

The aggregate command always runs the model and P1S builders. It runs the render
only when an executable explicit `XVFB_RUN_BIN` is available or `xvfb-run` is on
`PATH`; otherwise it warns and preserves the existing image.

## RED evidence

Added `RenderBuildTests.test_missing_xvfb_preserves_render_destination` to
`tests/test_release_scripts.py`. The test invokes:

```text
build-render.sh --output <temporary>/render.png
XVFB_RUN_BIN=/definitely/missing/xvfb-run
```

Before the implementation existed, the focused run failed at the intentional
entry-point assertion:

```text
FAIL ... scripts/build-render.sh is missing
```

This established that the test detected the missing production entry point.

## GREEN evidence

After implementing both scripts, the focused dependency test passed:

```text
python3 -m unittest tests.test_release_scripts.RenderBuildTests.test_missing_xvfb_preserves_render_destination -v
OK
```

The test verified that an invalid explicit Xvfb executable produces a nonzero
status, names `Xvfb`, includes the Ubuntu package URL, leaves no new output,
and preserves the existing sentinel bytes.

The real render command completed successfully:

```text
scripts/build-render.sh
python3 -m unittest tests.test_readme_render -v
Ran 2 tests ... OK
docs/bracket-render.png: PNG image data, 1200 x 900, 8-bit/color RGB, non-interlaced
```

An aggregate smoke test using isolated fake mandatory builders with
`XVFB_RUN_BIN=/definitely/missing/xvfb-run` returned status 0 and emitted:

```text
warning: Xvfb not found; keeping existing render
```

The tracked model and P1S artifacts were restored unchanged after that smoke
test; they are not part of this task's changes.

Final verification:

```text
sh -n scripts/build-render.sh scripts/build-all.sh
python3 -m unittest discover -s tests -v
Ran 34 tests in 53.863s
OK
git diff --check
```

The regenerated `docs/bracket-render.png` is a successful real OpenSCAD render
and remains 1200 × 900.

## Files changed

- `scripts/build-render.sh`
- `scripts/build-all.sh`
- `tests/test_release_scripts.py`
- `docs/bracket-render.png`
- this report

No SCAD source, profiles, neutral model exports, or sliced P1S artifact were
changed.

## Fix round 1: explicit Xvfb override precedence

### RED evidence

Added `AggregateBuildTests.test_invalid_explicit_xvfb_skips_render_even_when_path_has_xvfb`.
The isolated test copies `build-all.sh`, supplies fake model/P1S/render entry
points, places an executable fake `xvfb-run` on `PATH`, and sets
`XVFB_RUN_BIN=/definitely/missing/xvfb-run`. Against the previous aggregate
predicate, the focused test failed because the event log showed:

```text
['models', 'p1s', 'render']
```

This demonstrated that the invalid explicit override incorrectly fell through
to the PATH candidate and invoked rendering.

### GREEN evidence

`build-all.sh` now treats an explicitly set `XVFB_RUN_BIN` as authoritative:
only an executable override enables rendering; PATH lookup is used only when
the override is unset. The focused aggregate test and the direct-render strict
dependency test both pass:

```text
python3 -m unittest \
  tests.test_release_scripts.AggregateBuildTests.test_invalid_explicit_xvfb_skips_render_even_when_path_has_xvfb \
  tests.test_release_scripts.RenderBuildTests.test_missing_xvfb_preserves_render_destination -v
Ran 2 tests ... OK
```

The aggregate regression verifies mandatory builders run first, rendering is
not invoked, the exact warning is emitted, status is zero, and the existing
render sentinel remains byte-for-byte unchanged.

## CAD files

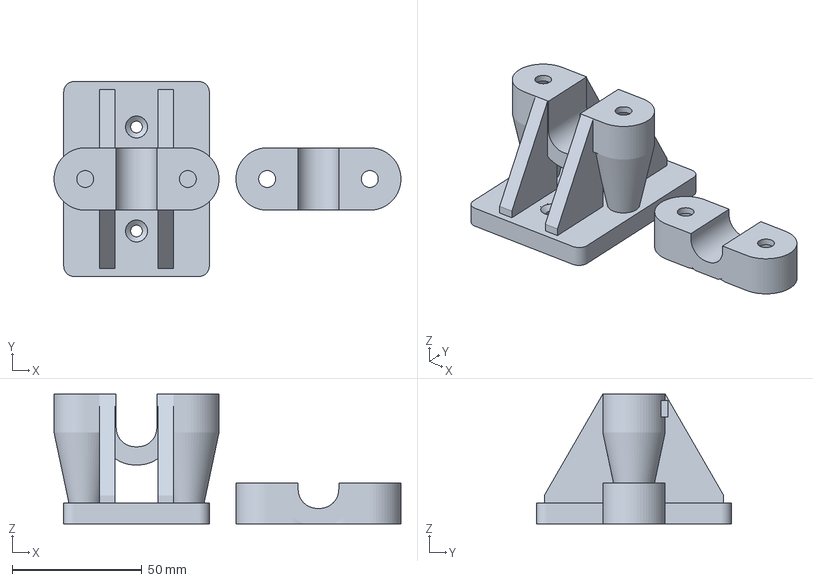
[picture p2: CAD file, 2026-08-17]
dist/models/wardrobe_rail_bracket_complete.3mf
133.5 x 75.0 x 50.0 mm

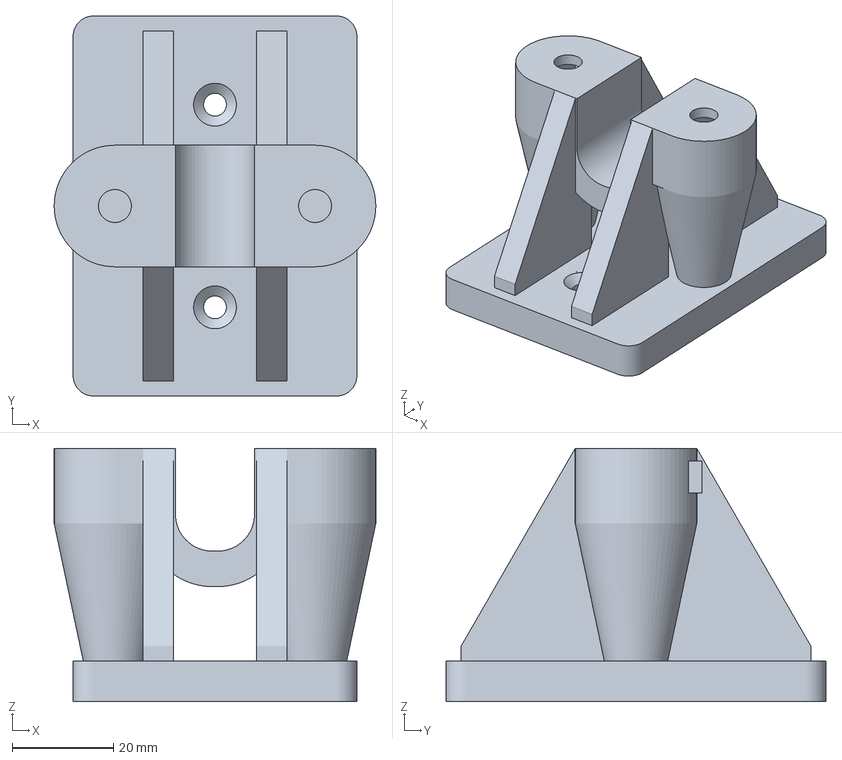
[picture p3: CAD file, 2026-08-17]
dist/models/wardrobe_rail_bracket_main.3mf
63.5 x 75.0 x 50.0 mm

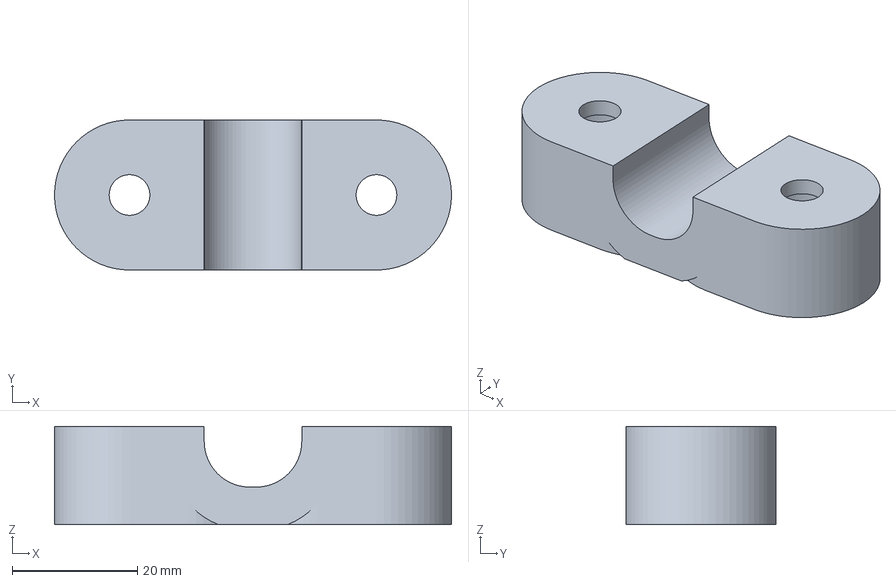
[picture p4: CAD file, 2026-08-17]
dist/models/wardrobe_rail_bracket_cap.3mf
63.5 x 24.0 x 15.7 mm

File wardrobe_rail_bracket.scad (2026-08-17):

/*
 * Ceiling-mounted clamp for a 30 x 15 mm wardrobe rail.
 *
 * Coordinate system in assembly mode:
 *   X: across the rail, Y: along the rail, Z: upward toward the ceiling.
 *   The ceiling-contact face is Z = 0 and the bracket hangs below it.
 *
 * Set `part` to "main_print" or "cap_print" for a directly sliceable STL.
 * The "main" and "cap" modes retain installed assembly coordinates.
 * The default "print" layout places both parts on the build plate.
 */

part = "print";                 // print/assembly/main/cap/main_print/cap_print

rail_width = 15;                // horizontal cross-section dimension
rail_height = 30;               // vertical cross-section dimension
rail_radius = 7;                // rounded-rectangle corner radius
rail_clearance = 0.3;           // clearance on each side
ceiling_gap = 30;               // ceiling to top of rail

plate_width = 56;
plate_length = 75;
plate_thickness = 8;
plate_corner_radius = 4;
ceiling_screw_diameter = 4.5;   // clearance for nominal 4 mm screws
ceiling_screw_spacing = 40;
ceiling_screw_head_diameter = 8.5;
ceiling_screw_access_clearance = 1;
ceiling_screw_angle = 90;

wall_thickness = 6;
clamp_depth = 24;               // length of clamp along the rail
clamp_gap = 0.6;                // closing gap between main body and cap
cap_capture_height = 10.3;      // rail height captured below the split
gusset_thickness = 6;
gusset_rail_clearance = 0.4;

clamp_bolt_diameter = 6;
clamp_bolt_length = 12;          // measured from beneath the button head
clamp_bolt_clearance = 0.5;
clamp_bolt_head_diameter = 11;   // clearance envelope for a 10.5 mm button head
clamp_bolt_head_height = 3.6;    // clearance envelope for a 3.3 mm button head
bolt_lug_radius = 12;
clamp_nut_across_flats = 10;
clamp_nut_thickness = 6;
nut_clearance = 0.3;
cap_bolt_seat_thickness = 2.5;
nut_floor_thickness = 2.5;
nut_roof_thickness = 6;
minimum_bolt_projection = 0;     // M6 x 12 reaches 0.1 mm beyond the 6.3 mm pocket
print_support_angle = 30;       // maximum boss overhang from vertical

$fn = 64;

// Derived dimensions. Changing the public rail parameters updates the clamp.
socket_width = rail_width + 2 * rail_clearance;
socket_height = rail_height + 2 * rail_clearance;
socket_radius = rail_radius + rail_clearance;
outer_width = socket_width + 2 * wall_thickness;
outer_height = socket_height + 2 * wall_thickness + 2;
outer_radius = socket_radius + wall_thickness;
rail_center_z = -(ceiling_gap + rail_height / 2);
split_relative_z = -socket_height / 2 + cap_capture_height;
split_z = rail_center_z + split_relative_z;
outer_profile_bottom_z = rail_center_z - outer_height / 2;
cap_floor_z = outer_profile_bottom_z + 1;
nut_corner_radius = (clamp_nut_across_flats + nut_clearance) / sqrt(3);
bolt_x = socket_width / 2 + wall_thickness
    + max(clamp_bolt_head_diameter / 2, nut_corner_radius);
nut_pocket_height = clamp_nut_thickness + nut_clearance;
nut_pocket_bottom_z = split_z + nut_floor_thickness;
nut_pocket_top_z = nut_pocket_bottom_z + nut_pocket_height;
main_lug_top_z = nut_pocket_top_z + nut_roof_thickness;
cap_top_z = split_z - clamp_gap;
bolt_seat_z = cap_top_z - cap_bolt_seat_thickness;
bolt_tip_z = bolt_seat_z + clamp_bolt_length;
bolt_head_recess_depth = bolt_seat_z - cap_floor_z;
boss_support_height = -plate_thickness - main_lug_top_z;
boss_support_min_radius =
    (clamp_bolt_diameter + clamp_bolt_clearance) / 2 + wall_thickness / 2;
boss_support_top_radius =
    max(
        boss_support_min_radius,
        bolt_lug_radius - boss_support_height * tan(print_support_angle)
    );
ceiling_countersink_depth =
    (ceiling_screw_head_diameter - ceiling_screw_diameter)
    / (2 * tan(ceiling_screw_angle / 2));

assert(
    part == "print" || part == "assembly" || part == "main" || part == "cap"
    || part == "main_print" || part == "cap_print",
    "part must be print, assembly, main, cap, main_print, or cap_print"
);
assert(rail_width > 0 && rail_height > 0, "rail dimensions must be positive");
assert(rail_radius > 0, "rail_radius must be positive");
assert(
    rail_radius <= min(rail_width, rail_height) / 2,
    "rail_radius must be at most half the smaller rail dimension"
);
assert(rail_clearance >= 0, "rail_clearance cannot be negative");
assert(wall_thickness >= 6, "wall_thickness must be at least 6 mm");
assert(ceiling_gap >= 0, "ceiling_gap cannot be negative");
assert(
    plate_width > 0 && plate_length > 0 && plate_thickness > 0,
    "plate dimensions must be positive"
);
assert(plate_thickness >= wall_thickness, "plate is thinner than wall_thickness");
assert(
    plate_corner_radius >= 0
    && plate_corner_radius <= min(plate_width, plate_length) / 2,
    "plate_corner_radius does not fit the plate"
);
assert(clamp_depth > 0, "clamp_depth must be positive");
assert(
    clamp_depth >= 2 * bolt_lug_radius,
    "clamp_depth must be at least the bolt lug diameter"
);
assert(
    gusset_thickness >= wall_thickness,
    "gusset_thickness must be at least wall_thickness"
);
assert(gusset_rail_clearance >= 0, "gusset_rail_clearance cannot be negative");
assert(
    ceiling_screw_diameter > 0
    && ceiling_screw_head_diameter > ceiling_screw_diameter,
    "ceiling screw dimensions are invalid"
);
assert(
    ceiling_screw_angle > 0 && ceiling_screw_angle < 180,
    "ceiling_screw_angle must be between 0 and 180 degrees"
);
assert(
    ceiling_countersink_depth > 0 && ceiling_countersink_depth < plate_thickness,
    "ceiling countersink does not fit the plate"
);
assert(ceiling_screw_access_clearance >= 0, "ceiling screw access clearance is negative");
assert(
    ceiling_screw_spacing + ceiling_screw_head_diameter <= plate_length - 4,
    "ceiling screw spacing does not fit the plate"
);
assert(
    clamp_bolt_diameter > 0
    && clamp_bolt_length > 0
    && clamp_bolt_clearance >= 0
    && clamp_bolt_head_diameter > clamp_bolt_diameter
    && clamp_bolt_head_height > 0,
    "clamp bolt dimensions are invalid"
);
assert(
    clamp_nut_across_flats > 0
    && clamp_nut_thickness > 0
    && nut_clearance >= 0,
    "nut dimensions are invalid"
);
assert(
    cap_bolt_seat_thickness >= 2.5 && nut_floor_thickness >= 2.5,
    "bolt and nut bearing webs must be at least 2.5 mm thick"
);
assert(
    nut_roof_thickness >= wall_thickness,
    "not enough material above the captive nut"
);
assert(
    minimum_bolt_projection >= 0,
    "minimum bolt projection cannot be negative"
);
assert(
    bolt_lug_radius >= clamp_bolt_head_diameter / 2 + wall_thickness,
    "bolt lug is too small around the bolt head"
);
assert(
    bolt_lug_radius >= nut_corner_radius + wall_thickness,
    "bolt lug is too small around the captive nut"
);
assert(
    bolt_head_recess_depth >= clamp_bolt_head_height,
    "button head does not fit inside the cap recess"
);
assert(
    bolt_tip_z - nut_pocket_top_z >= minimum_bolt_projection,
    "clamp bolt is too short to engage the captive nut"
);
assert(
    bolt_tip_z <= main_lug_top_z,
    "clamp bolt extends beyond the main bolt lug"
);
assert(
    print_support_angle > 0 && print_support_angle <= 30,
    "print_support_angle must be between 0 and 30 degrees"
);
assert(boss_support_height > 0, "bolt boss support height must be positive");
assert(
    boss_support_top_radius >= boss_support_min_radius,
    "bolt boss support is too narrow at the plate"
);
assert(
    bolt_x + boss_support_top_radius <= plate_width / 2,
    "bolt boss support must begin within the ceiling plate"
);
assert(
    plate_width >= outer_width,
    "plate_width must cover the upper saddle"
);
assert(
    bolt_x - nut_corner_radius - socket_width / 2 >= wall_thickness,
    "not enough material between socket and captive nut"
);
assert(
    bolt_x - clamp_bolt_head_diameter / 2 - socket_width / 2 >= wall_thickness,
    "not enough material between socket and bolt head"
);
assert(
    cap_capture_height > rail_radius && cap_capture_height < socket_height / 2,
    "cap_capture_height must place the split on a straight side of the socket"
);
assert(clamp_gap >= 0 && clamp_gap < 2, "clamp_gap must be between 0 and 2 mm");


module rounded_rectangle_2d(size, radius) {
    assert(radius <= min(size) / 2, "rounded rectangle radius is too large");
    hull() {
        for (x = [-size[0] / 2 + radius, size[0] / 2 - radius])
            for (y = [-size[1] / 2 + radius, size[1] / 2 - radius])
                translate([x, y]) circle(r = radius);
    }
}


module extrude_along_y(length) {
    rotate([90, 0, 0])
        linear_extrude(height = length, center = true, convexity = 10)
            children();
}


module centered_cube(size) {
    translate([-size[0] / 2, -size[1] / 2, -size[2] / 2]) cube(size);
}


module plate_positive() {
    translate([0, 0, -plate_thickness])
        linear_extrude(height = plate_thickness)
            rounded_rectangle_2d([plate_width, plate_length], plate_corner_radius);
}
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

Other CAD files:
dist/models/wardrobe_rail_bracket_cap.stl
dist/models/wardrobe_rail_bracket_main.stl

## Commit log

2026-08-16 docs: replace bracket schematic with SCAD render
2026-08-16 feat: adapt bracket for M6 clamp hardware
    [wardrobe_rail_bracket.scad]
2026-08-16 build: publish current M6 model files
    [wardrobe_rail_bracket.3mf, wardrobe_rail_bracket_cap.3mf, wardrobe_rail_bracket_cap.stl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]
2026-08-16 build: regenerate P1S release with OrcaSlicer
    [p1s-0.4-machine.json]
2026-08-16 fix: validate staged release artifacts
2026-08-17 docs: design 6 mm nut clearance
2026-08-17 docs: plan 6 mm nut clearance
2026-08-17 fix: fit 6 mm captive nuts
    [wardrobe_rail_bracket.scad]
2026-08-17 build: refresh 6 mm nut model assets
    [wardrobe_rail_bracket_cap.3mf, wardrobe_rail_bracket_cap.stl, wardrobe_rail_bracket_complete.3mf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]
2026-08-17 build: refresh 6 mm nut P1S project
2026-08-17 feat: increase ceiling gap to 30 mm
    [wardrobe_rail_bracket.scad]
2026-08-17 build: refresh 30 mm gap model assets
    [wardrobe_rail_bracket_cap.3mf, wardrobe_rail_bracket_cap.stl, wardrobe_rail_bracket_complete.3mf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]
2026-08-17 build: refresh 30 mm gap P1S project
